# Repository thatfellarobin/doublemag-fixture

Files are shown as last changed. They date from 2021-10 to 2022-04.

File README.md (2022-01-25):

# doublemag-fixture
stuff for my double magnet fixture

## Working with z-offset
When  the sample is not at the same height as the magnets, i.e. there is an offset in the z axis, a different control mode is used.
Z offset at some key landmarks are listed:

- To bottom side of t slot aluminum: 33.66 mm
- To bottom side of t slot aluminum plus additional 1/16": 35.2 mm
- To bottom side of t slot aluminum plus additional 1/8": 36.84 mm

## Issues when running on ubuntu:

- https://askubuntu.com/questions/308128/failed-to-load-platform-plugin-xcb-while-launching-qt5-app-on-linux-without >> run `sudo apt-get install --reinstall libxcb-xinerama0`

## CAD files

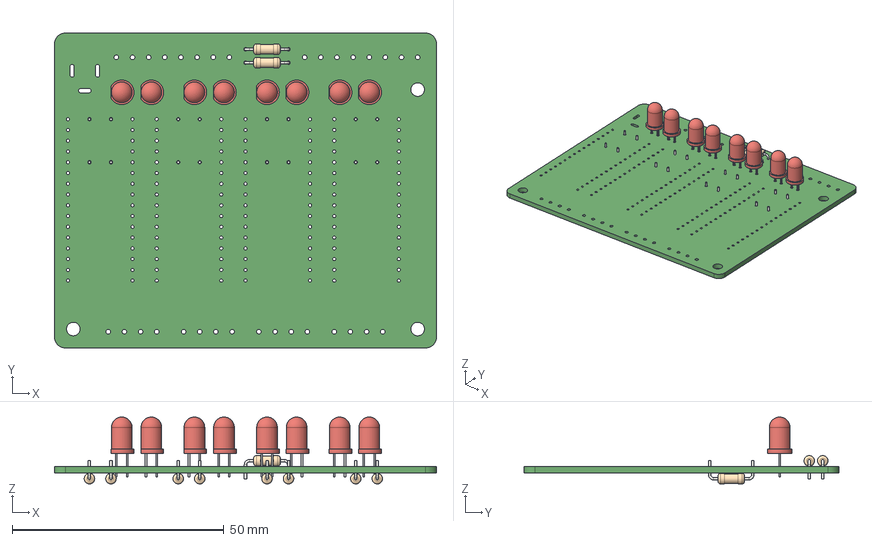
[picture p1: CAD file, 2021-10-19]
doublemagfixture/3d/doublemagfixture.step
90.2 x 74.3 x 15.8 mm

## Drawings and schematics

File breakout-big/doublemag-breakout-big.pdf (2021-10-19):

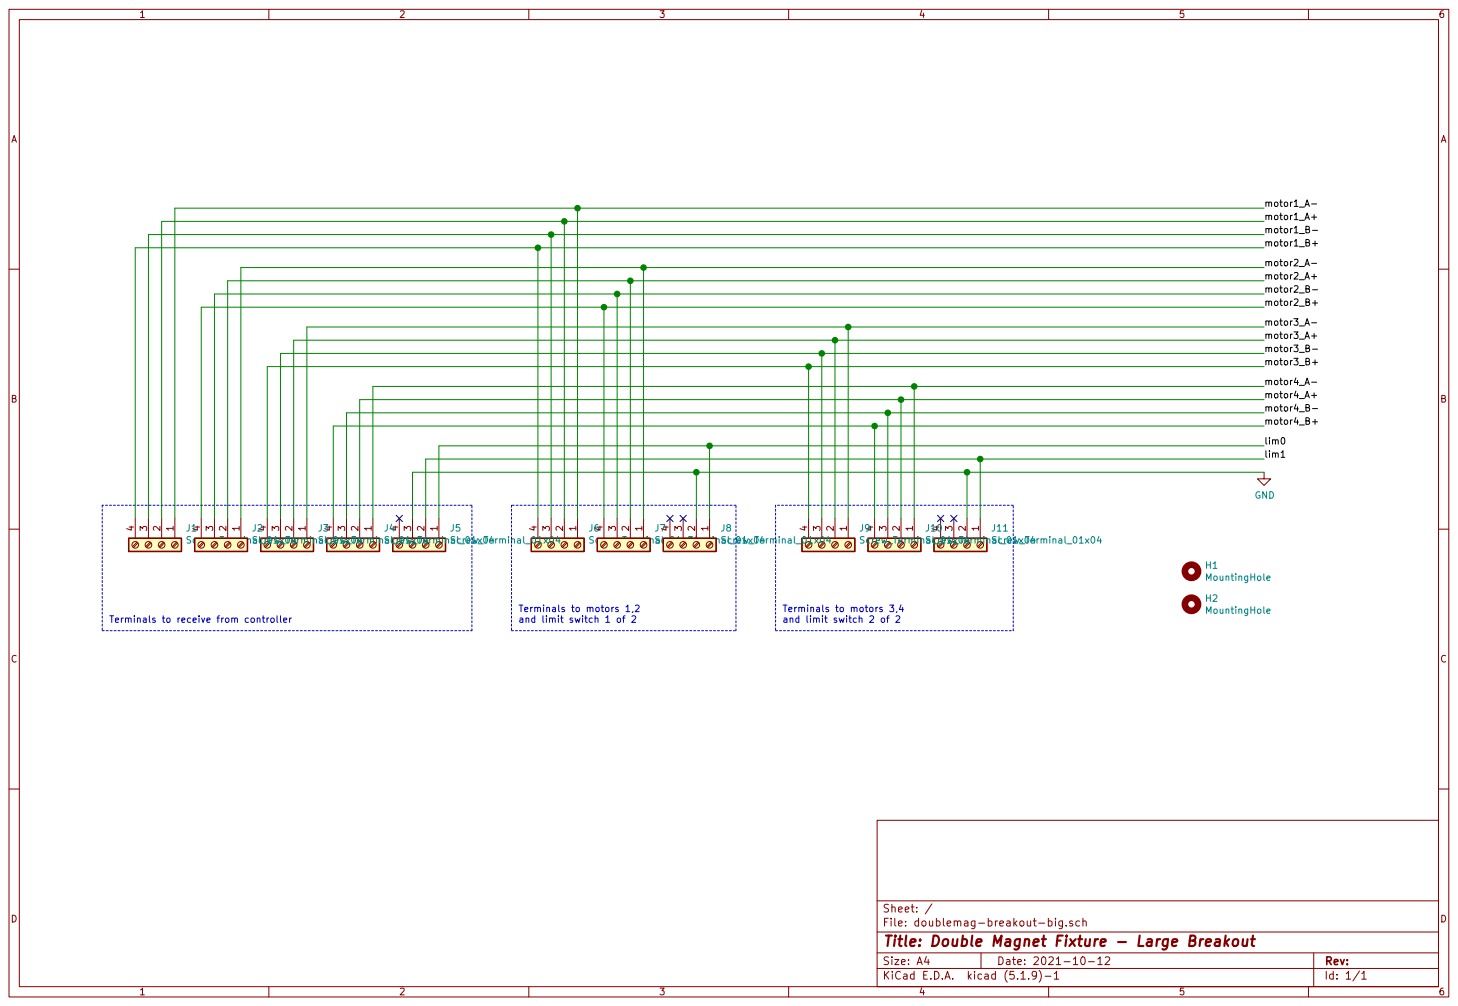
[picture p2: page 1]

and limit switch 2 of 2

File: doublemag-breakout-big.sch Sheet: /
Id: 1/1 Title: Double Magnet Fixture - Large Breakout

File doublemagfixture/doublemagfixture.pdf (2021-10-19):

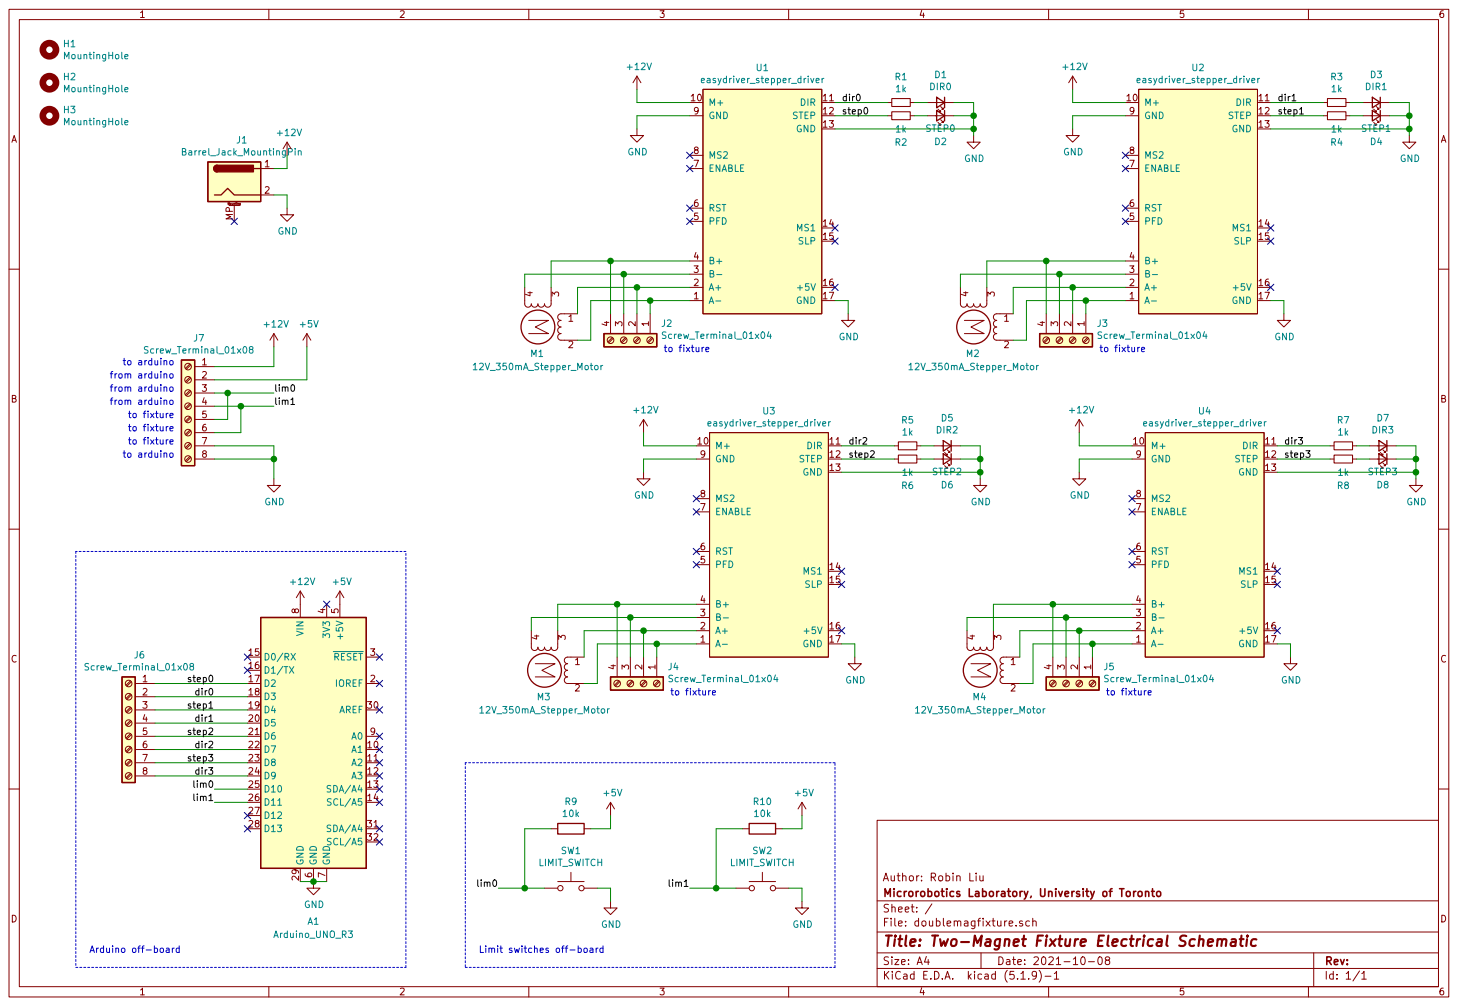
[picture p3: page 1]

to fixture Arduino off-board

File: doublemagfixture.sch Sheet: / Microrobotics Laboratory, University of Toronto Author: Robin Liu

Id: 1/1 Title: Two-Magnet Fixture Electrical Schematic

Limit switches off-board

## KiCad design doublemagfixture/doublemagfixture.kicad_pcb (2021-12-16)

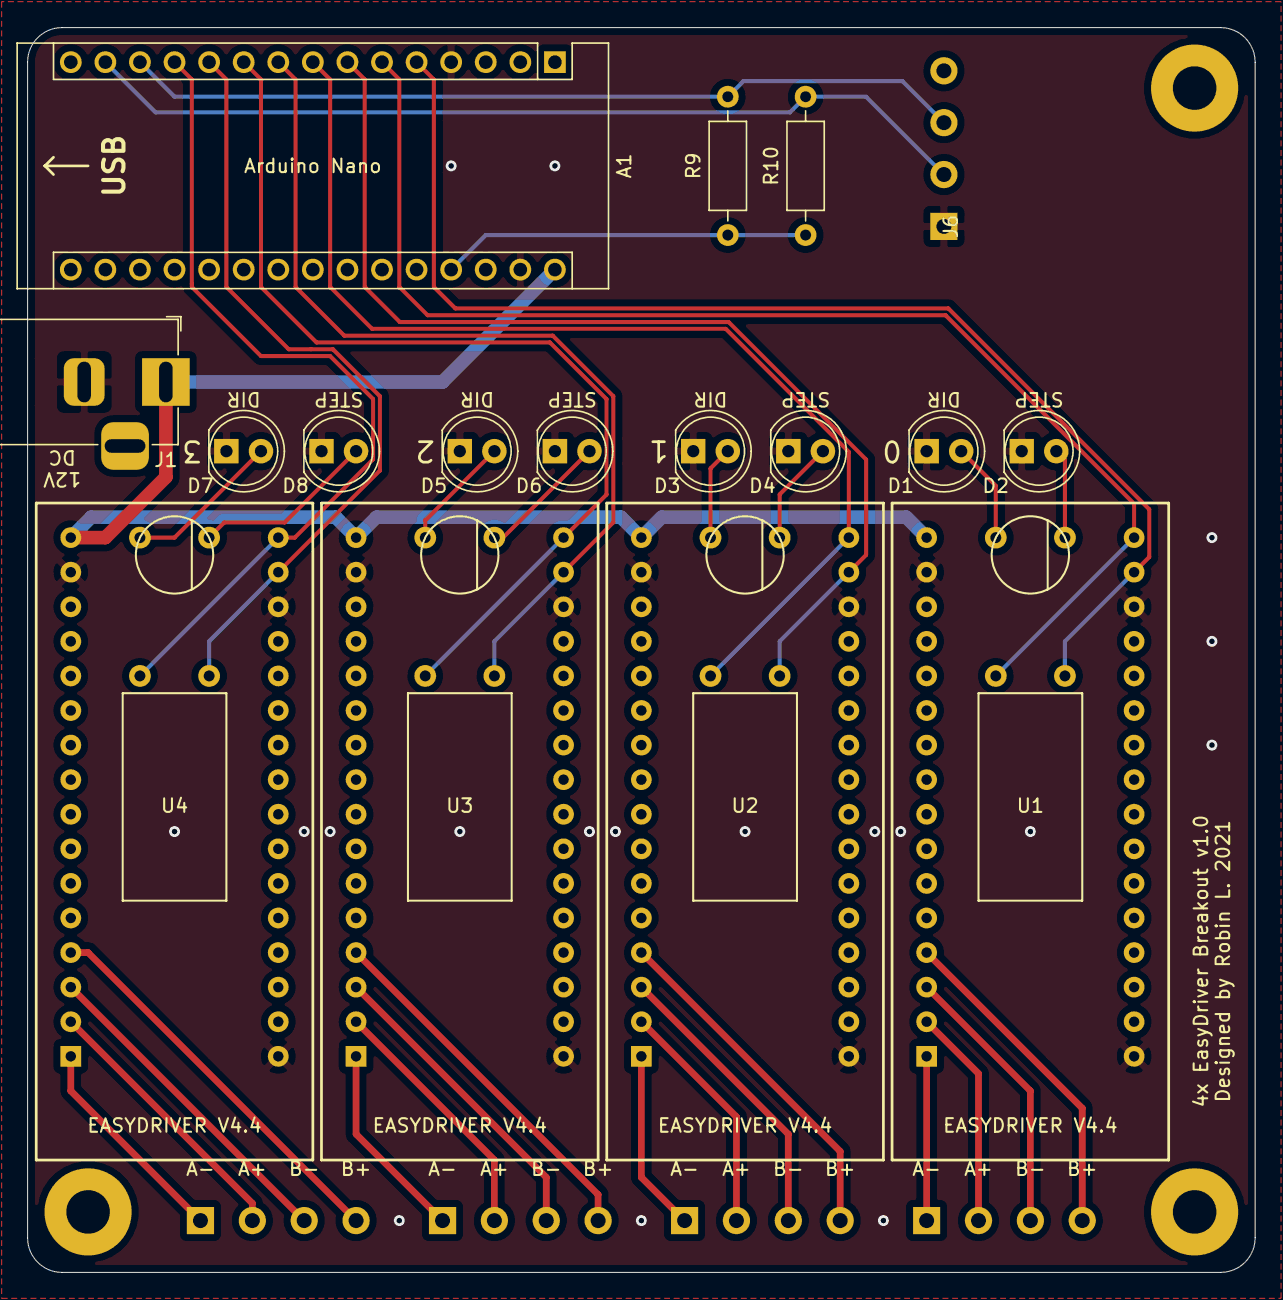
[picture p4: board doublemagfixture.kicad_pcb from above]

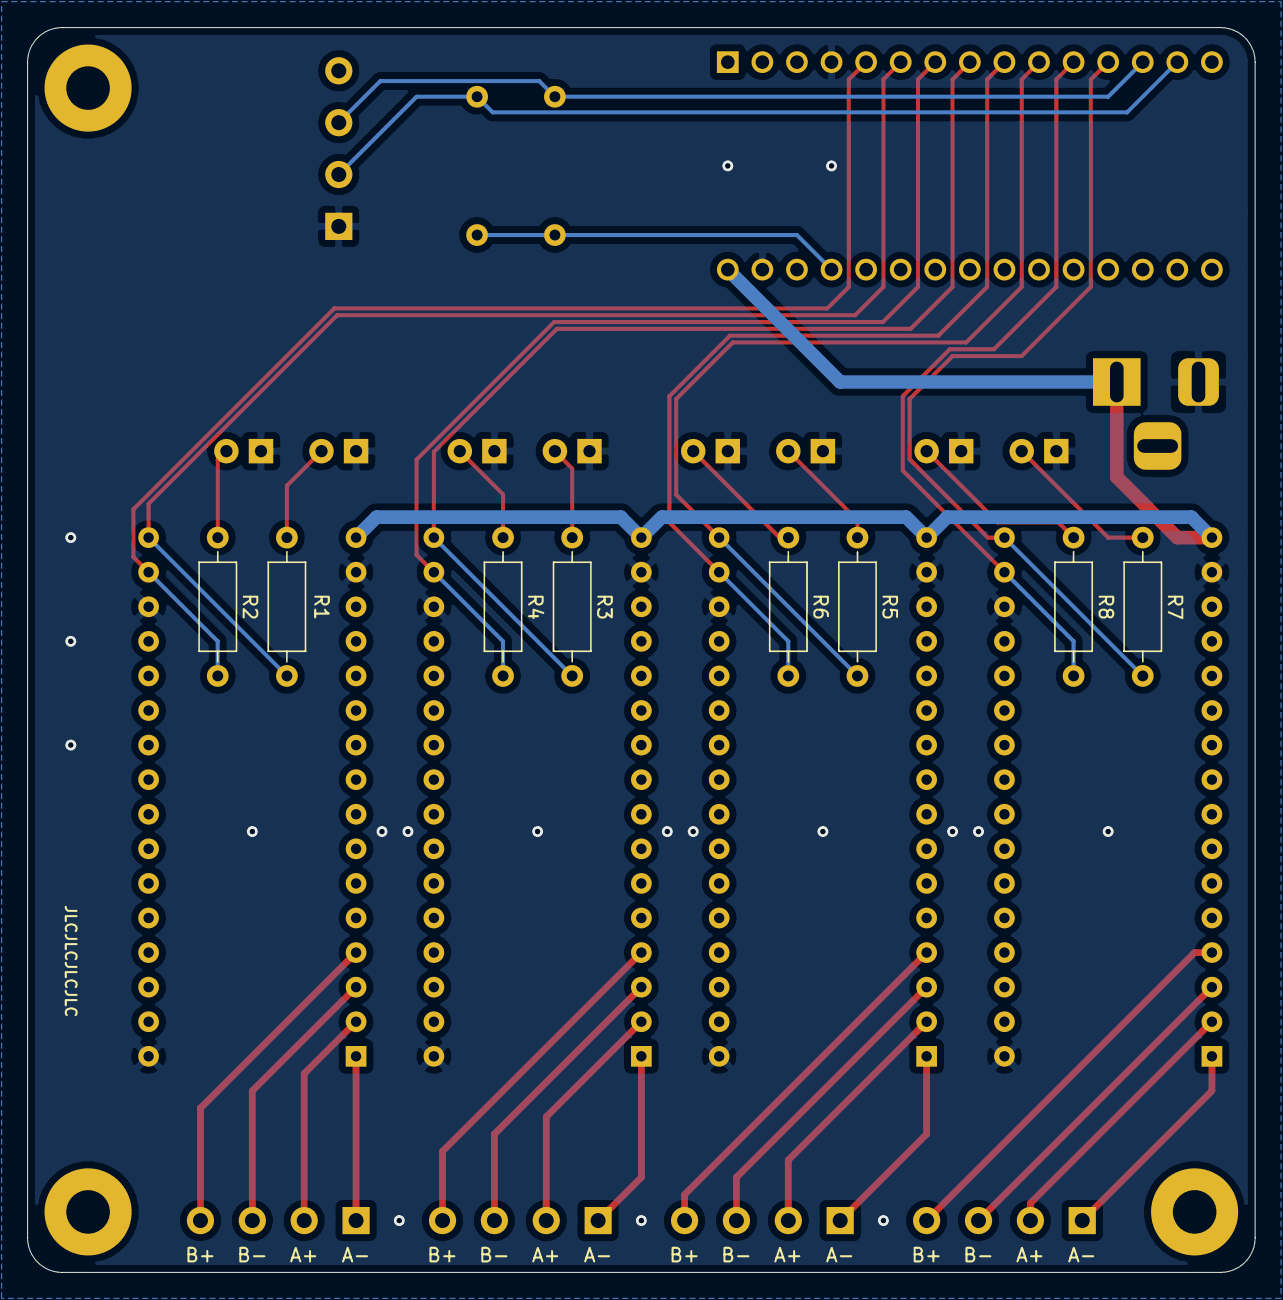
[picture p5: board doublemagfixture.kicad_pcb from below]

Board: 2 copper layers, 90.2 x 91.4 mm, 32 parts (8 on the bottom side), 37 nets.

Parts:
A1: Arduino_Nano_v3.x; Arduino_Nano
D1: DIR0; LED_D5.0mm
D2: STEP0; LED_D5.0mm
D3: DIR1; LED_D5.0mm
D4: STEP1; LED_D5.0mm
D5: DIR2; LED_D5.0mm
D6: STEP2; LED_D5.0mm
D7: DIR3; LED_D5.0mm
D8: STEP3; LED_D5.0mm
H1, H2, H3: MountingHole; MountingHole_3.2mm_M3_Pad
J1: Barrel_Jack_MountingPin; BarrelJack_Horizontal
J2, J3, J4, J5, J6: Screw_Terminal_01x04; CONN_1x4_3.81mm
R1, R2, R3, R4, R5, R6, R7, R8: 1k; R_Axial_DIN0207_L6.3mm_D2.5mm_P10.16mm_Horizontal
R9, R10: 10k; R_Axial_DIN0207_L6.3mm_D2.5mm_P10.16mm_Horizontal
U1, U2, U3, U4: easydriver_stepper_driver; easydriver_V44

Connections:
+5V: A1.27, R9.1, R10.1
+12V: A1.30, J1.1, U1.10, U2.10, U3.10, U4.10
/dir0: A1.6, R1.2, U1.11
/dir1: A1.8, R3.2, U2.11
/dir2: A1.10, R5.2, U3.11
/dir3: A1.12, R7.2, U4.11
/lim0: A1.13, J6.3, R9.2
/lim1: A1.14, J6.2, R10.2
/step0: A1.5, R2.2, U1.12
/step1: A1.7, R4.2, U2.12
/step2: A1.9, R6.2, U3.12
/step3: A1.11, R8.2, U4.12
GND: A1.4, A1.29, D1.1, D2.1, D3.1, D4.1, D5.1, D6.1, D7.1, D8.1, J1.2, J6.1, U1.9, U1.13, U1.17, U2.9, U2.13, U2.17, U3.9, U3.13, U3.17, U4.9, U4.13, U4.17
unnamed: D1.2, R1.1
unnamed: D2.2, R2.1
unnamed: D3.2, R3.1
unnamed: D4.2, R4.1
unnamed: D5.2, R5.1
unnamed: D6.2, R6.1
unnamed: D7.2, R7.1
unnamed: D8.2, R8.1
unnamed: J2.1, U1.1
unnamed: J2.2, U1.2
unnamed: J2.3, U1.3
unnamed: J2.4, U1.4
unnamed: J3.1, U2.1
unnamed: J3.2, U2.2
unnamed: J3.3, U2.3
unnamed: J3.4, U2.4
unnamed: J4.1, U3.1
unnamed: J4.2, U3.2
unnamed: J4.3, U3.3
unnamed: J4.4, U3.4
unnamed: J5.1, U4.1
unnamed: J5.2, U4.2
unnamed: J5.3, U4.3
unnamed: J5.4, U4.4

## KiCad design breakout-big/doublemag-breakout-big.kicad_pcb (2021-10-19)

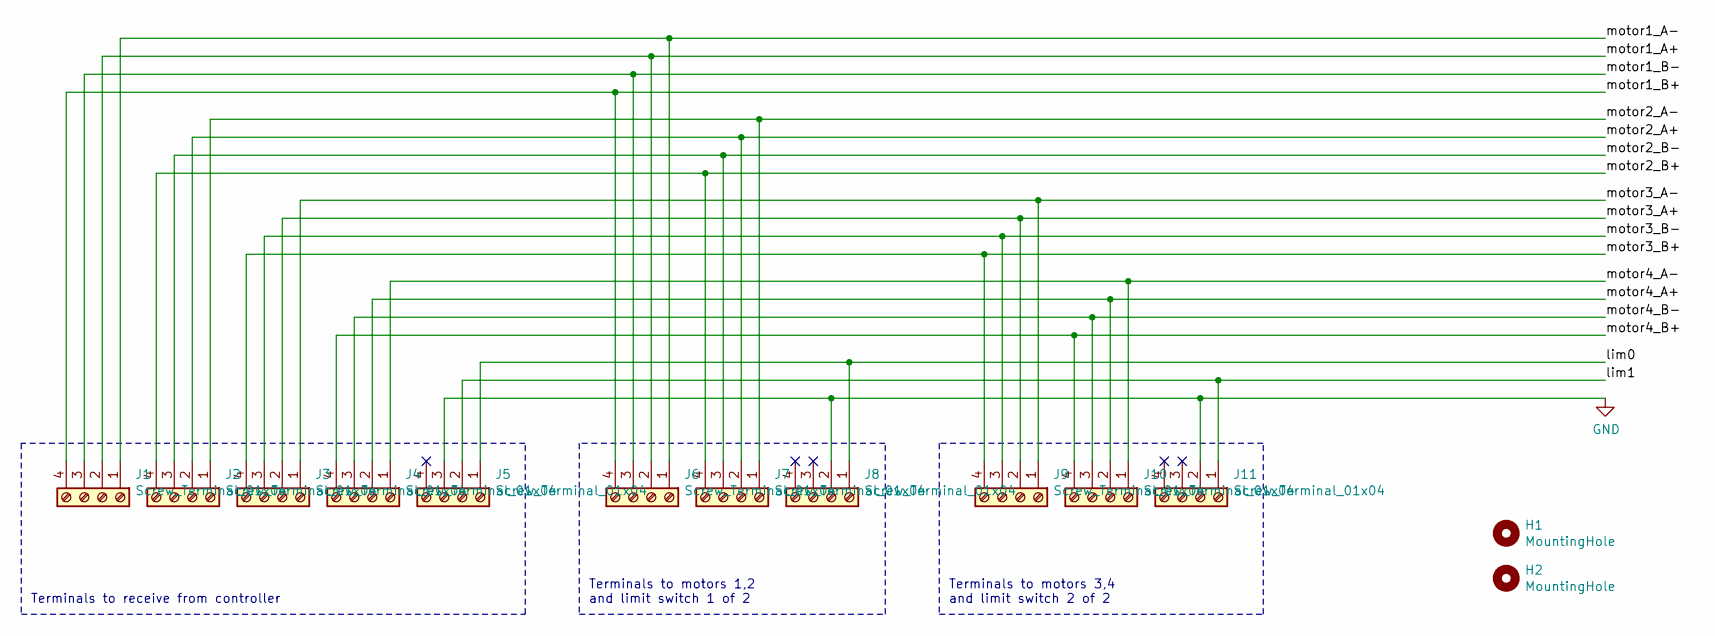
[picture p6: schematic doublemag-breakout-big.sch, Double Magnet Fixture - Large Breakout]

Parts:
H1, H2: MountingHole; MountingHole_3.2mm_M3_Pad
J1, J2, J3, J4, J5, J6, J7, J8, J9, J10, J11: Screw_Terminal_01x04; CONN_1x4_3.81mm

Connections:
/lim0: J5.1, J8.1
/lim1: J5.2, J11.1
/motor1_A+: J1.2, J6.2
/motor1_A-: J1.1, J6.1
/motor1_B+: J1.4, J6.4
/motor1_B-: J1.3, J6.3
/motor2_A+: J2.2, J7.2
/motor2_A-: J2.1, J7.1
/motor2_B+: J2.4, J7.4
/motor2_B-: J2.3, J7.3
/motor3_A+: J3.2, J9.2
/motor3_A-: J3.1, J9.1
/motor3_B+: J3.4, J9.4
/motor3_B-: J3.3, J9.3
/motor4_A+: J4.2, J10.2
/motor4_A-: J4.1, J10.1
/motor4_B+: J4.4, J10.4
/motor4_B-: J4.3, J10.3
GND: J5.3, J8.2, J11.2

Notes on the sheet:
Terminals to receive from controller
Terminals to motors 3,4 and limit switch 2 of 2
Terminals to motors 1,2 and limit switch 1 of 2

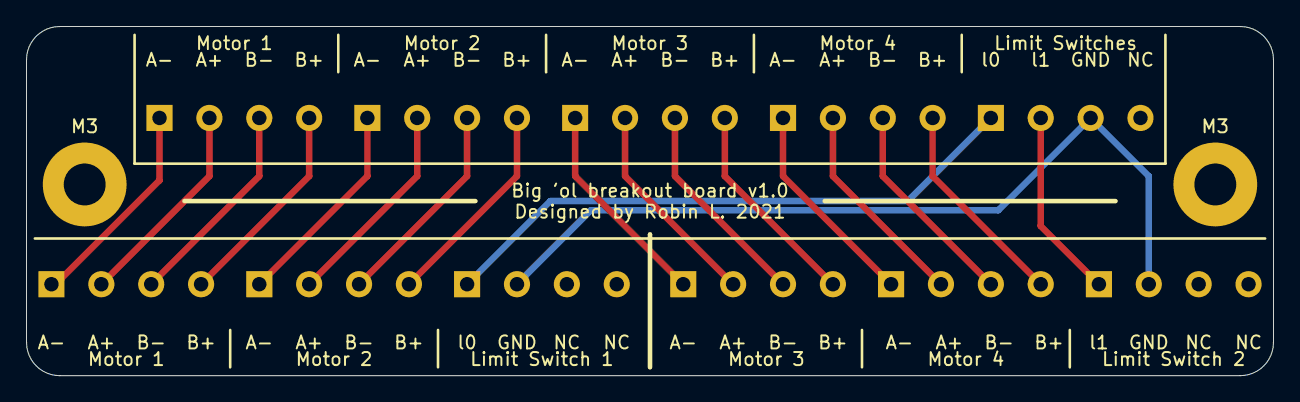
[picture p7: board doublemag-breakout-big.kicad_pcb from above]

Board: 2 copper layers, 95.3 x 26.7 mm, 13 parts (0 on the bottom side), 19 nets.

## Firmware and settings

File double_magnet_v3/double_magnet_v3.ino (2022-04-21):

/*
Author: Robin Liu

This sketch controls four stepper motors through EasyDriver or similar driver boards.
It listens for serial input containing instructions for running the motors and executes those instructions.

Notes on movement and directionality:
- Positive # of steps rotates the motor shaft clockwise as viewed from the motor body.
- For the linear axis, clockwise rotation moves the magnet away from the workspace
- Linear: (200*8) steps per rev / 8 mm per rev = 200 steps per mm
- Angular: (200*8) steps per rev / 360 deg per rev = 4.44 steps per deg

- For the magnetic field sensor, positive y points towards the front of the fixture, and positive z points downwards

Attribution:
- Code for serial interfacing from here: https://forum.arduino.cc/index.php?topic=288234.0

TODO:
- Make sure degrees are used throughout instead of radians
- Mag field angle can be rotated 180 deg without consequence. Adjust for this?
- Polarity of magnets and magnetic sensor are yet to be resolved.
*/

// Includes
#include <AccelStepper.h>

// PINS
const int stepPins[] = {2, 4, 6, 8};
const int dirPins[] = {3, 5, 7, 9};
const int motorCount = 4;
const int limitPins[] = {10, 11}; // Pull-up resistors used.

// Serial message variables
const byte msgNumChars = 32;
char receivedChars[msgNumChars];
bool newMsg = false; // flag to indicate if a new message has arrived
char msgType = 's';
int activemotor = 0;
int manualsteps = 0;

// Data reporting variables
unsigned long currentTime;
unsigned long previousReportTime;
unsigned long previousMagsenseTime;
const unsigned int reportingTimeInterval = 200; // milliseconds between outgoing messages


// Motor control
AccelStepper Motor_A(AccelStepper::DRIVER, stepPins[0], dirPins[0]);
AccelStepper Motor_B(AccelStepper::DRIVER, stepPins[1], dirPins[1]);
AccelStepper Motor_C(AccelStepper::DRIVER, stepPins[2], dirPins[2]);
AccelStepper Motor_D(AccelStepper::DRIVER, stepPins[3], dirPins[3]);

//###########################################
//###########################################

void setup() {
  // Set up motor settings. These can be tuned to the desired performance.
  Motor_A.setMaxSpeed(1200);
  Motor_A.setAcceleration(700);
  Motor_B.setMaxSpeed(400);
  Motor_B.setAcceleration(500);
  Motor_C.setMaxSpeed(400);
  Motor_C.setAcceleration(500);
  Motor_D.setMaxSpeed(1200);
  Motor_D.setAcceleration(700);

  // Set up limit switch pins
  pinMode(limitPins[0], INPUT);
  pinMode(limitPins[1], INPUT);

  // Set up serial
  Serial.begin(9600);
  Serial.println("Serial ready");

  // Start timer
  currentTime = millis();
  previousReportTime = millis();
}

void loop() {
  currentTime = millis();

  // # Check for new messages in serial port
  recvWithEndMarker();

  // # Check if a new position command has been issued.
  if (newMsg == true) {
    msgType = parseMsg();
    newMsg = false;
  }

  // # Decide on the target position
  // Consider the following:
  // 1. External commands
  // 2. Limit switch signals
  // 3. Other safety stops (field maxima, etc.)

  // (1) For a valid message, set motor target in accordance with the message
  setStepTarget(msgType);
  msgType = (msgType=='m' ? 'e' : msgType); // only run a manual command once
  // (2) adjust target for limit switches.
  if (!digitalRead(limitPins[0]) && Motor_A.targetPosition()-Motor_A.currentPosition() > 0) {
    // Don't use .stop() here, it doesn't work as well because it accounts for the set speed not being 0
    Motor_A.moveTo(Motor_A.currentPosition());
  }
  if (!digitalRead(limitPins[1]) && Motor_D.targetPosition()-Motor_D.currentPosition() > 0) {
    // Don't use .stop() here, it doesn't work as well because it accounts for the set speed not being 0
    Motor_D.moveTo(Motor_D.currentPosition());
  }

  // # Run motors
  runMotors();

  // # Handle periodic data reporting
  if (currentTime - previousReportTime > reportingTimeInterval) {
    previousReportTime = currentTime;
    writeTelemetry();
  }
}

void recvWithEndMarker() {
  static byte ndx = 0;
  char endMarker = '\n';
  char rc;

  while (Serial.available() > 0 && newMsg == false) {
    rc = Serial.read();

    if (rc != endMarker) {
      receivedChars[ndx] = rc;
      ndx++;
      if (ndx >= msgNumChars) {
        ndx = msgNumChars - 1;
      }
    }
    else { // end marker character was received
      receivedChars[ndx] = '\0'; // terminate the string
      ndx = 0;
      newMsg = true;
    }
  }
}

char parseMsg() {
  /*
  Read through the received message

  # Message descriptions:
  byte 1: one byte indicating the message type

  ## Message type 's': stop immediately

  ## Message type 'm': manual control
  byte 2: motor index (0, 1, 2, 3)
  byte 3-7: 5 char string: number of steps (absolute step target)
  byte 8: direction of motion; '-' if negative and anything else for positive.

  returns: the message type. 'e' for invalid msg.
  */

  bool validMsg = true;
  float fluxTarget_temp = 0;
  float angleTarget_temp = 0;

  int newDigit = 0;

  if (receivedChars[0] == 's') {
    // Stop immediately
    return 's';
  }
  else if (receivedChars[0] == 'm') {
    // Manual control
    activemotor = receivedChars[1] - '0';
    manualsteps = 0;

    for (int i = 2; i < 7; i++) {
      // read # steps
      newDigit = receivedChars[i]-'0';
      if (newDigit >= 0 && newDigit <= 9) {
        manualsteps = (10 * manualsteps) + newDigit;
      }
      else {
        validMsg = false;
        break;
      }
    }
    if (receivedChars[7] == '-') {
      manualsteps = -manualsteps;
    }
    if (validMsg) {
      return 'm';
    }
  }
  else {
    validMsg = false;
  }

  if (validMsg == false) {
    Serial.println("invalid msg");
    return 'e';
  }
}

void runMotors() {
  // to be called as often as possible
  Motor_A.run();
  Motor_B.run();
  Motor_C.run();
  Motor_D.run();
}

void setStepTarget(byte msgType) {
  if (msgType == 's') {
    Motor_A.moveTo(Motor_A.currentPosition());
    Motor_B.moveTo(Motor_B.currentPosition());
    Motor_C.moveTo(Motor_C.currentPosition());
    Motor_D.moveTo(Motor_D.currentPosition());
  }
  else if (msgType == 'm') {
    // Note: non active motors are not stopped. If they are to be stopped,
    // then an explicit command should be sent from the external controller
    if (activemotor == 0) {
      Motor_A.moveTo(manualsteps);
    }
    else if (activemotor == 1) {
      Motor_B.moveTo(manualsteps);
    }
    else if (activemotor == 2) {
      Motor_C.moveTo(manualsteps);
    }
    else if (activemotor == 3) {
      Motor_D.moveTo(manualsteps);
    }
  }
}

void writeTelemetry() {
  // Send messages through serial to connected computer

  // Report motor positions
  Serial.print("data,");
  Serial.print(Motor_A.currentPosition());
  Serial.print(",");
  Serial.print(Motor_B.currentPosition());
  Serial.print(",");
  Serial.print(Motor_C.currentPosition());
  Serial.print(",");
  Serial.print(Motor_D.currentPosition());
  Serial.print(",");
  // Report limit switch status
  Serial.print(digitalRead(limitPins[0]) ? "0" : "1"); // Pull-up resistor
  Serial.print(",");
  Serial.print(digitalRead(limitPins[1]) ? "0" : "1"); // Pull-up resistor
  // End the message
  Serial.print("\r\n");
}

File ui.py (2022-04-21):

import serial
import numpy as np
import os
import time
from datetime import datetime
from scipy.io import loadmat

from PyQt5 import uic
from PyQt5.QtCore import QTimer
from PyQt5.QtWidgets import QMainWindow

# from subthreads import Thread_Wiggler

#=========================================================
# UI Setup
#=========================================================
qtCreatorFile = 'doublemag.ui'
Ui_MainWindow, QtBaseClass = uic.loadUiType(qtCreatorFile)
MSG_HISTORY_LENGTH = 3

#=========================================================
# Serial Info
#=========================================================
ARDUINO_PORT = '/dev/tty.usbmodem141301' # macOS - Robin's MBP as well (?)
# ARDUINO_PORT = '/dev/tty.usbserial-AC00921Z' # macOS - Robin's MBP
# ARDUINO_PORT = 'COM8' # Windows - Lab Microscope PC
ARDUINO_BAUD = 9600

#=========================================================
# Magnet Calibration Info
#=========================================================
Z_OFFSET = 35.2 # z-offset in mm, from height of magnet centre to height of sample
if Z_OFFSET == 0:
    MAGNET_CALIB_MATFILE = 'two_mag_constangle_field_17.27Am2.mat'
else:
    MAGNET_CALIB_MATFILE = f'two_mag_3D_17.27Am2_{Z_OFFSET}mmZoffset.mat'


#=========================================================
# Stepper and Motor Info
#=========================================================
MICROSTEP_FACTOR = 8.0
MOTOR_STEPS_PER_REV = 200.0
STEPS_PER_REV = MICROSTEP_FACTOR * MOTOR_STEPS_PER_REV
MM_PER_REV = 8.0

SMALL_MANUAL_STEPS_LINEAR = (0.25 / MM_PER_REV) * STEPS_PER_REV
SMALL_MANUAL_STEPS_ANGULAR = (0.5 / 360) * STEPS_PER_REV
BIG_MANUAL_STEPS_LINEAR = (5 / MM_PER_REV) * STEPS_PER_REV
BIG_MANUAL_STEPS_ANGULAR = (5 / 360) * STEPS_PER_REV

class DoubleMagnetGUI(QMainWindow, Ui_MainWindow):
    # Notes on direction
    # - Positive # of steps rotates the motor shaft clockwise as viewed from the motor body.
    # - For the linear axis, clockwise rotation moves the magnet away from the workspace

    # Notes on units
    # - fixture records position in mm
    def __init__(self):
        QMainWindow.__init__(self)
        Ui_MainWindow.__init__(self)
        self.setupUi(self)
        self.setupTimer()
        self.initTime = time.time() # Helpful in some cases to have a global reference time

        # Status flags
        self.isManualControl = False
        self.isAborted = True
        self.isDataRecording = False

        # UI connections - main buttons
        self.button_resetField.clicked.connect(self.resetField)
        self.button_abort.clicked.connect(self.abortMotion)
        self.button_zeroing.clicked.connect(self.beginZeroing)
        self.button_recordData.clicked.connect(self.toggleDataRecording)
        # UI connections - manual controls
        self.button_motorA_l.clicked.connect(self.motorA_l)
        self.button_motorA_r.clicked.connect(self.motorA_r)
        self.button_motorB_u.clicked.connect(self.motorB_u)
        self.button_motorB_d.clicked.connect(self.motorB_d)
        self.button_motorC_u.clicked.connect(self.motorC_u)
        self.button_motorC_d.clicked.connect(self.motorC_d)
        self.button_motorD_l.clicked.connect(self.motorD_l)
        self.button_motorD_r.clicked.connect(self.motorD_r)
        self.button_motorA_l_2.clicked.connect(self.motorA_l_2)
        self.button_motorA_r_2.clicked.connect(self.motorA_r_2)
        self.button_motorB_u_2.clicked.connect(self.motorB_u_2)
        self.button_motorB_d_2.clicked.connect(self.motorB_d_2)
        self.button_motorC_u_2.clicked.connect(self.motorC_u_2)
        self.button_motorC_d_2.clicked.connect(self.motorC_d_2)
        self.button_motorD_l_2.clicked.connect(self.motorD_l_2)
        self.button_motorD_r_2.clicked.connect(self.motorD_r_2)
        # UI connections - check box
        self.checkBox_wigglemode.stateChanged.connect(lambda: self.wiggleToggle(self.checkBox_wigglemode))

        # Create serial connection
        self.ser = serial.Serial(ARDUINO_PORT, ARDUINO_BAUD, timeout=1)

        # Variables to track motor position
        self.motor_step_0 = np.array([0., 0., 0., 0.])
        self.motor_step = np.array([0., 0., 0., 0.])
        self.motor_pos_0 = np.array([0., 0., 0., 0.])
        self.motor_pos = np.array([0., 0., 0., 0.])
        self.limitSwitchStatus = [0, 0]

        # Variables to track magnetic reading
        self.mag = np.array([0., 0.]) # magnitude (mT) and angle (deg)

        # Load calibration matfile
        matfile = loadmat(MAGNET_CALIB_MATFILE)
        if Z_OFFSET == 0:
            mat_r = np.squeeze(matfile['r']) * 1000 # Convert m to mm
            mat_B = np.squeeze(matfile['B_map_norm']) * 1000 # Convert T to mT
            self.mat_r_rev = np.flip(mat_r) # np.interp requires increasing xp array as per documentation, this is for that case
            self.mat_B_rev = np.flip(mat_B) # np.interp requires increasing xp array as per documentation, this is for that case
        else:
            self.mat_map = np.squeeze(matfile['mag_angles_and_positions'])

        self.new_msg = ''
        self.msg_history = ['']

    def abortMotion(self):
        # send stop signal
        self.sendStop()

        # Turn off wiggle
        self.checkBox_wigglemode.setChecked(False)

        # lock out controls,
        # prevent sending further field values
        self.isAborted = True

    def beginZeroing(self):
        # User must manually navigate to the zeroing point and then hit the zeroing button

        zeroing_point=195
        zeroing_separation=45.75

        # Zero the linear axis
        self.motor_pos_0[0] = zeroing_point - zeroing_separation
        self.motor_pos_0[3] = zeroing_point - zeroing_separation

        # Zero the rotary axis
        self.motor_pos_0[1] = 0
        self.motor_pos_0[2] = 0


        # Match zeroed position with zeroed steps.
        for i in range(4):
            self.motor_step_0[i] = self.motor_step[i]

        print(zeroing_point)
        print(zeroing_separation)
        print(self.motor_pos_0)
        print(self.motor_step_0)

    def toggleDataRecording(self):
        '''
        sets/unsets data recording flag, so that self.update() can know if it's supposed to be recording data or not
        '''
        datetime_string = datetime.today().strftime('%Y-%m-%d_%H-%M-%S')
        time_string = datetime.today().strftime('%H:%M:%S.%f')
        maxmsglines = 2

        if not self.isDataRecording:
            self.fout = open(f'doublemagdata_{datetime_string}.txt', 'a')
            self.fout.write(f'started at {time_string}\n')
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

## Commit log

2021-02-03 basic functionality to read mag sensor data
2021-02-12 some more work on arduino sketch
2021-02-18 added stop signal and fixed some bugs
    [double_magnet_v3.ino, ui.py]
2021-02-22 limit switch communications
2021-02-24 configure for pull-up resistors on lim switches
2021-02-24 debugging arduino sketch
2021-03-05 removed mag sensing from arduino sketch
2021-03-22 added more buttons to ui
2021-04-14 add stop data recording button
2021-04-14 separate stop recording button was not a good idea
2021-04-15 added wiggle mode, fixed a data recording bug
    [ui.py]
2021-04-21 remove a print
2021-05-06 fixed wiggling frequency issue
    [ui.py]
2021-06-08 remove subthreads.py
    This file was the original plan for handling threaded tasks, but I ended
    up not needing it
2021-10-08 add kicad
    [doublemagfixture.kicad_pcb, doublemagfixture.sch]
2021-10-09 add kicad libs
2021-10-09 almost done pcb
    [doublemagfixture.kicad_pcb, doublemagfixture.sch]
2021-10-09 Final(?) pcb
    [doublemagfixture.kicad_pcb, doublemagfixture.sch]
2021-10-09 numbering fixes and wider traces on power line
    [doublemagfixture.kicad_pcb, doublemagfixture.sch]
2021-10-09 moved leds to front
    [doublemagfixture.kicad_pcb]
2021-10-12 export gerber and drill files
    [doublemagfixture-B_Cu.gbl, doublemagfixture-B_Cu.gbr, doublemagfixture-B_Mask.gbr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]
2021-10-12 change LED to 5mm
    [doublemagfixture-B_Cu.gbl, doublemagfixture-B_Cu.gbr, doublemagfixture-B_Mask.gbr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]
2021-10-19 add breakout board and reconfigure main board
    [doublemag-breakout-big-B_Cu.gbl, doublemag-breakout-big-B_Mask.gbs, doublemag-breakout-big-B_Paste.gbp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]
2021-10-29 fix bug with incoming serial parsing
    [ui.py]
2021-12-16 add 3D mag work
    [doublemagfixture.kicad_pcb, doublemagfixture.sch]
2021-12-20 working prototype?
2022-01-03 bugfix
    was erroneously interpolating on field strength instead of angle
    [ui.py]
2022-04-21 update wiggle mode
    wiggle mode now behaves more predictably. instead of trying to follow a
    sine wave, it moves between end stops with some pause at the limits.
    also updated the arduino code to push the motors faster, which allows
    for higher wiggle frequencies.
